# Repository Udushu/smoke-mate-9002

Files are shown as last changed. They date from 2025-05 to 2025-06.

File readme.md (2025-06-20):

# SmokeMATE 

## PARTS

1. Airflow Damper
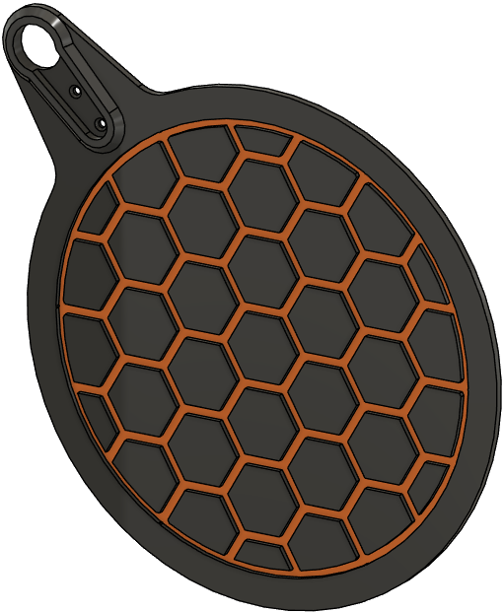
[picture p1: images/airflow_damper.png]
Airflow Damper
 

2. Blower Housing
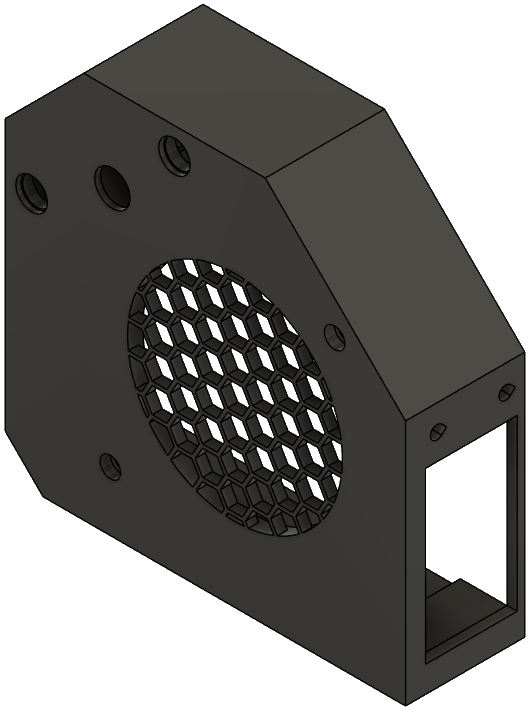
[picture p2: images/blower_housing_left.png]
Blower Housing Left

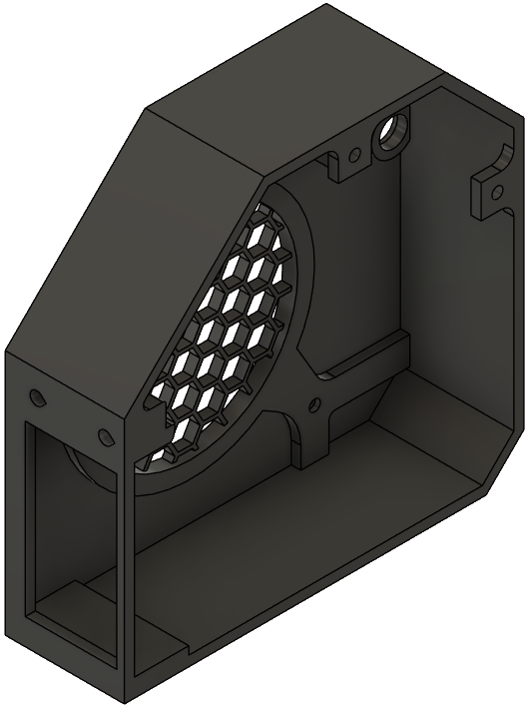
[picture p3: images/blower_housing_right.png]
Blower Housing Right


3. Blower Housing Screw Access Plug
Blower Housing Screw Access Plug

4. Blower Interface Adapter
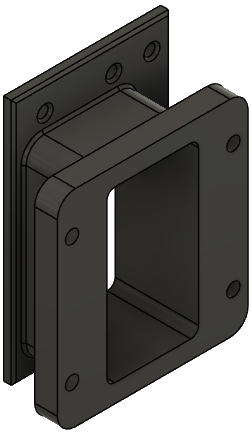
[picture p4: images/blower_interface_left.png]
Blower Interface Adapter Left

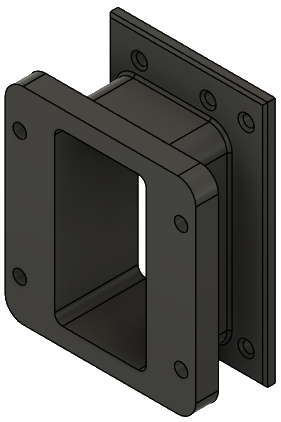
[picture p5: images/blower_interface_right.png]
Blower Interface Adapter Right


5. Control Knob
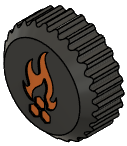
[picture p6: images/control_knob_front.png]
Control Knob Front

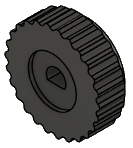
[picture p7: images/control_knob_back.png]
Control Knob Back


6. Display Housing
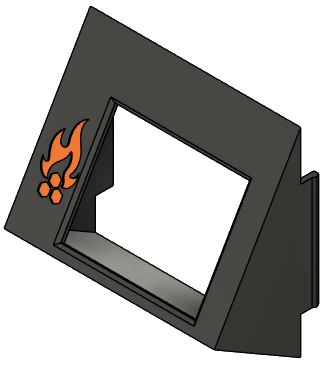
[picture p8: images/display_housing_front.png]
Display Housing Front

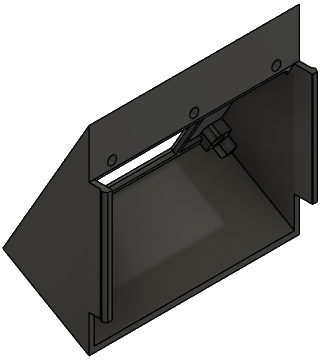
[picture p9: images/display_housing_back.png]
Display Housing Back

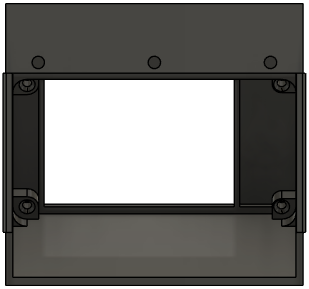
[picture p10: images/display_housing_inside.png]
Display Housing Inside


7. Electronics Housing
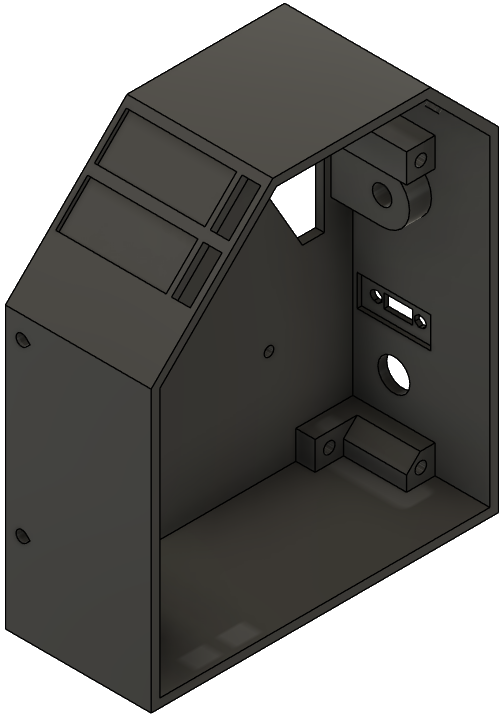
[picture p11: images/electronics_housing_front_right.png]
Electronics Housing Front Right

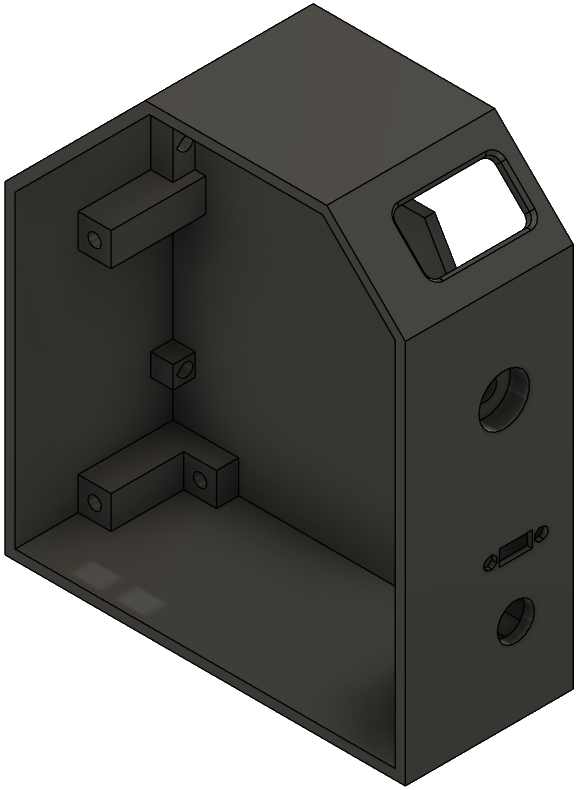
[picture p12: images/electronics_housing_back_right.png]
Electronics Housing Back Right

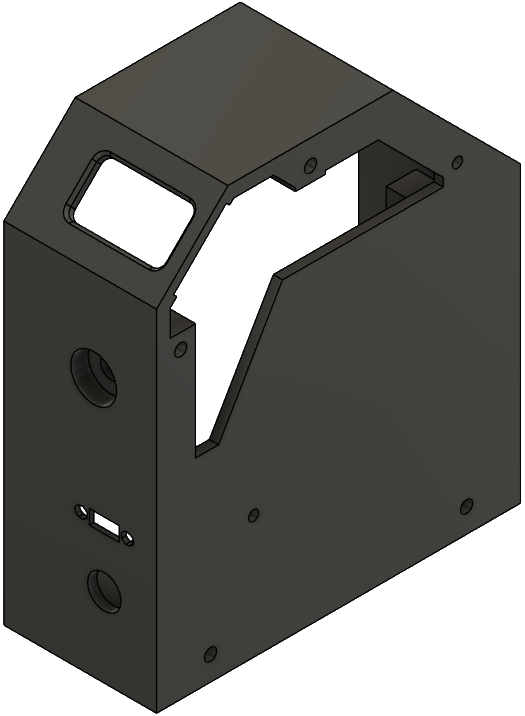
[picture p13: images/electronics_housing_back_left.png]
Electronics Housing Back Left


8. Electronics Lid
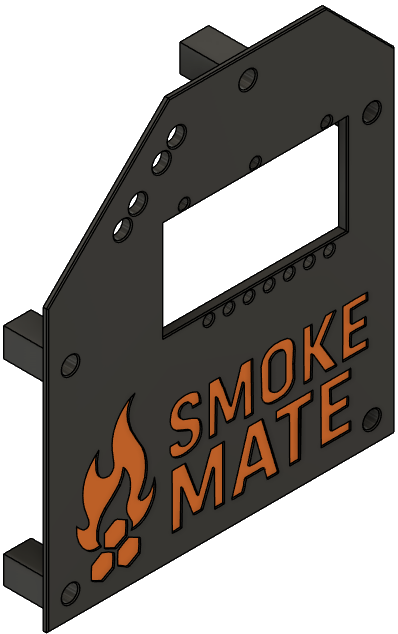
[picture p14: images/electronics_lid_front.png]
Electronics Lid Front

Electronics Lid Back

9. Electronics Mounting Panel
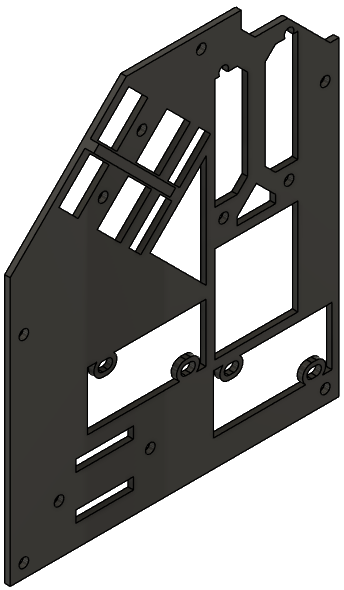
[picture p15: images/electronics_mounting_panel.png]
Electronics Mounting Panel


10. Encoder Access Plug
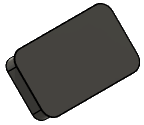
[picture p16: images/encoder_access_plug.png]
Encoder Access Plug


11. Supports
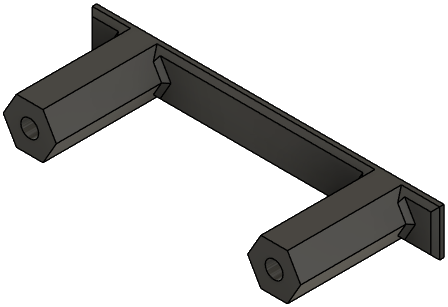
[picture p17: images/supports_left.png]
Supports Left

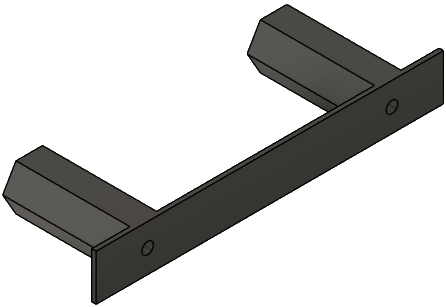
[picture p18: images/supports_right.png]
Supports Right


12. Blower Driver Holders
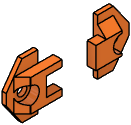
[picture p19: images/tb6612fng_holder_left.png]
Blower Driver Holders Left

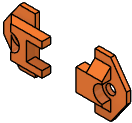
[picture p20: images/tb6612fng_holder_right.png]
Blower Driver Holders Right

Blower Driver Holders Front

13. Thermometer Labels
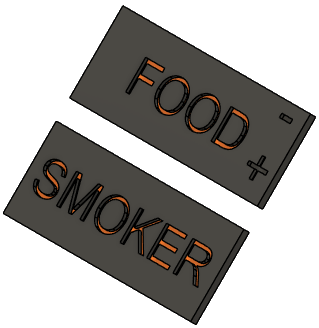
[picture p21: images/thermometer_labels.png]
Thermometer Labels


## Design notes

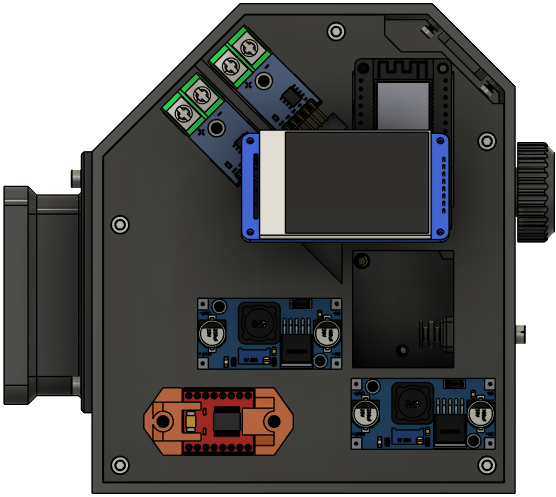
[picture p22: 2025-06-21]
images/smokemate_electronics_with_display.png

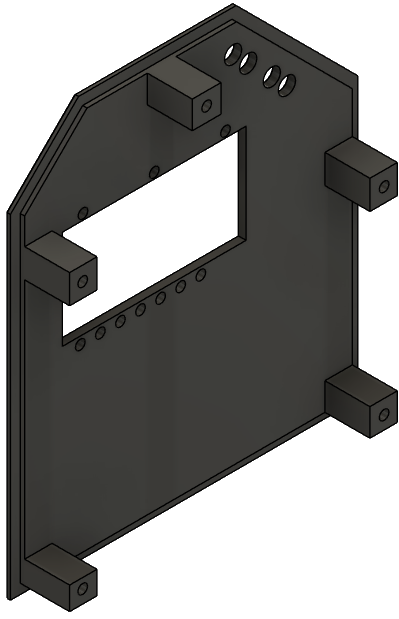
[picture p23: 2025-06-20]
images/electronics_lid_back.png

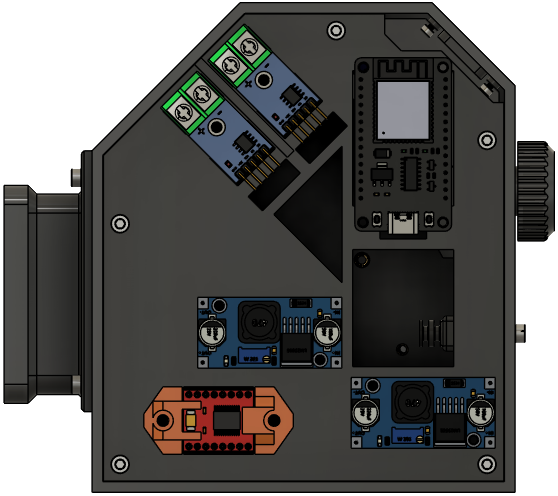
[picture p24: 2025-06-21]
images/smokemate_electronics_no_display.png

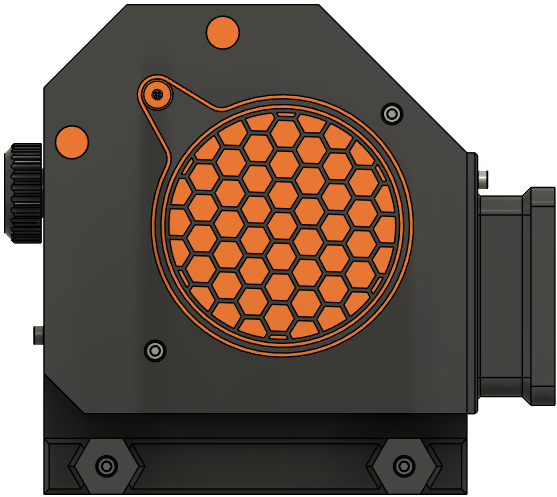
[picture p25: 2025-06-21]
images/smokemate_left.png

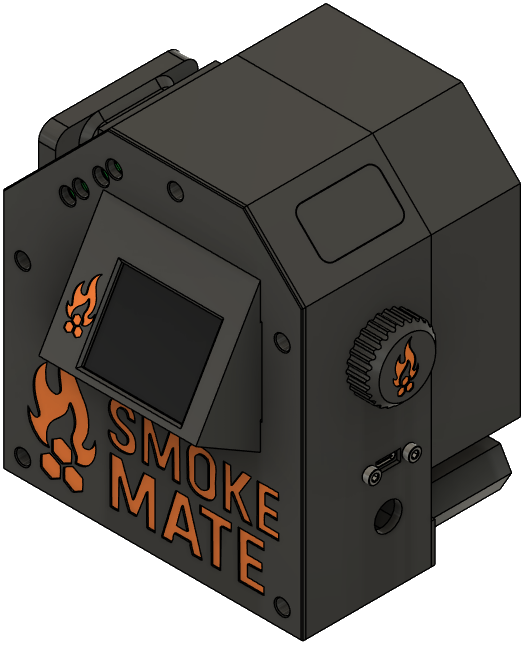
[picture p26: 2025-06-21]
images/smokemate_back_right.png

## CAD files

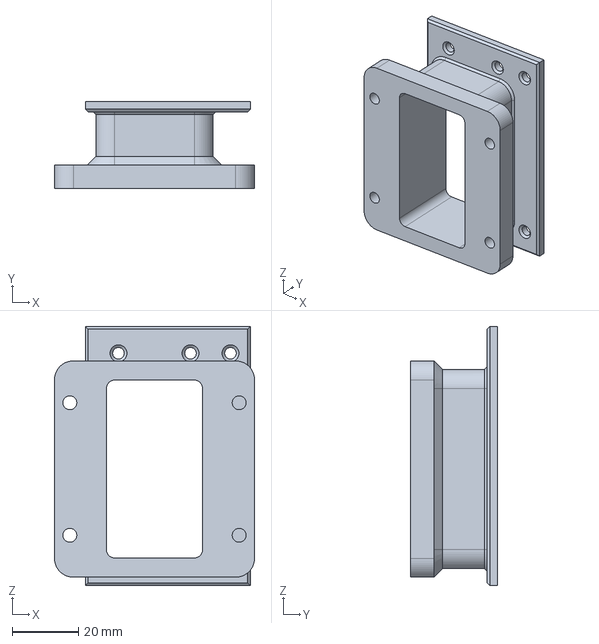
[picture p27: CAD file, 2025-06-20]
hardware/blower_interface.step
60.4 x 26.4 x 78.2 mm

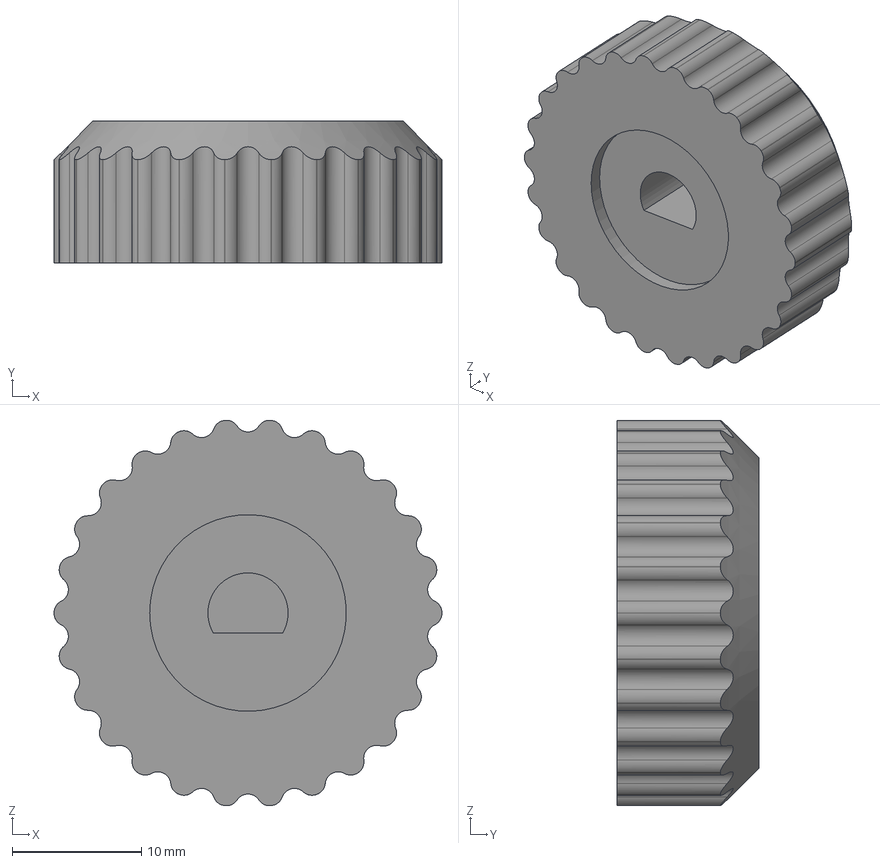
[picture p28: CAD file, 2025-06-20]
hardware/control_knob.step
30.0 x 11.0 x 29.8 mm

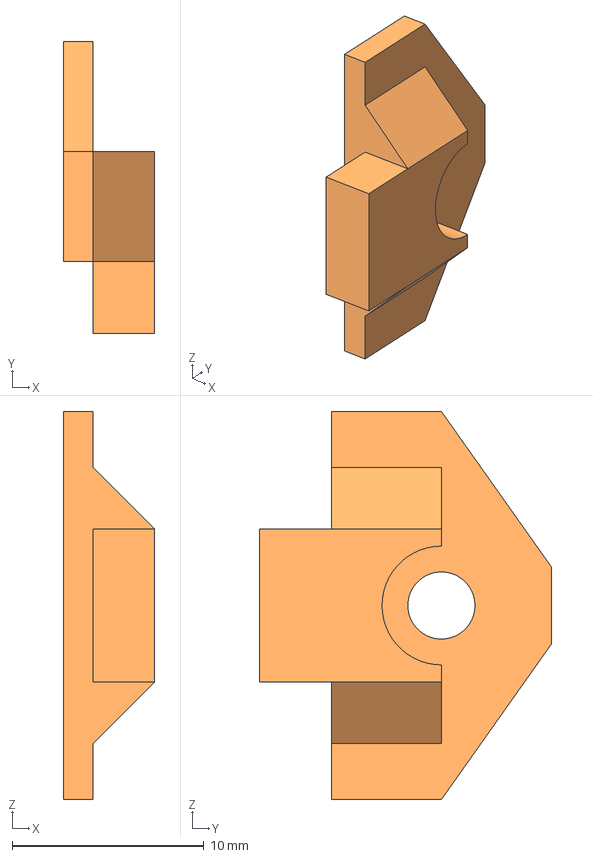
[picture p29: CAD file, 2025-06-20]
hardware/TB6612FNG_holder_right.step
4.75 x 15.3 x 20.2 mm

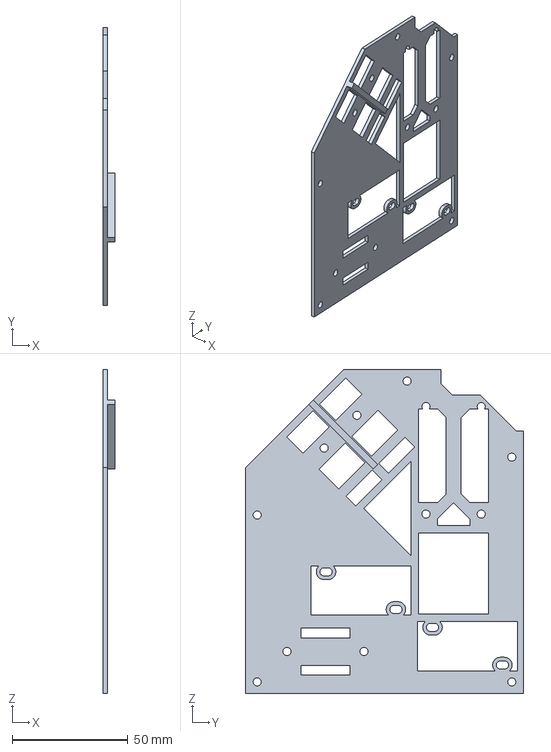
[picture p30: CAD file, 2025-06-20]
hardware/electronics_mounting_panel.step
5.20 x 120.0 x 140.0 mm

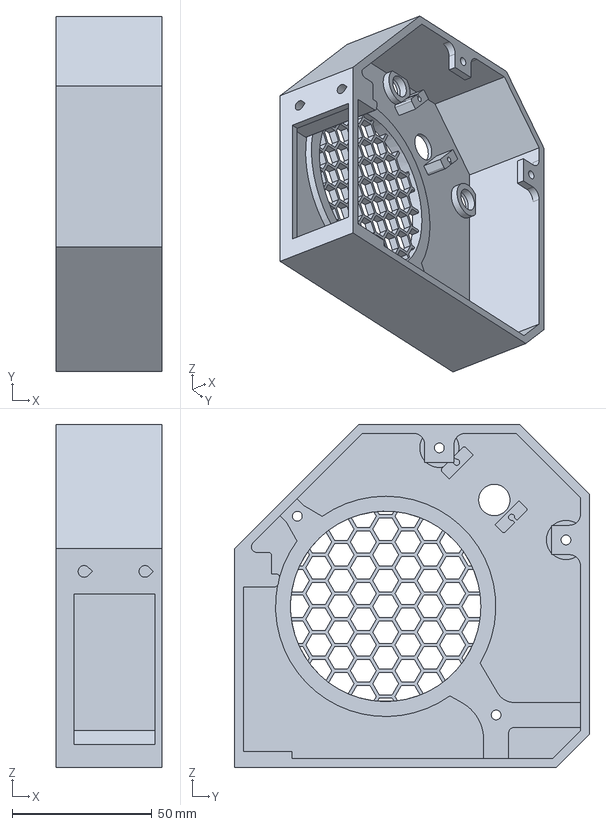
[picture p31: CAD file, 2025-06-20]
hardware/blower_housing.step
37.8 x 126.8 x 122.6 mm

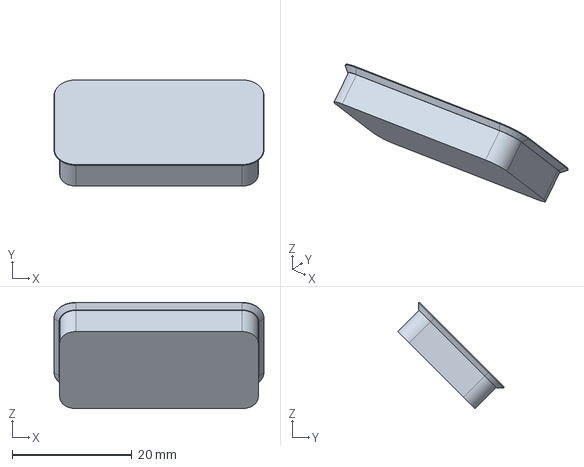
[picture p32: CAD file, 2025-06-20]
hardware/encoder_access_plug.step
35.1 x 17.7 x 17.7 mm

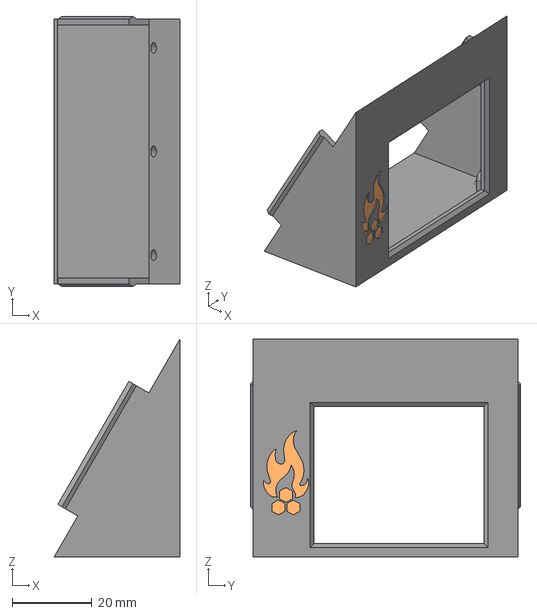
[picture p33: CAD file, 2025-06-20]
hardware/display_housing.step
31.6 x 67.8 x 54.7 mm

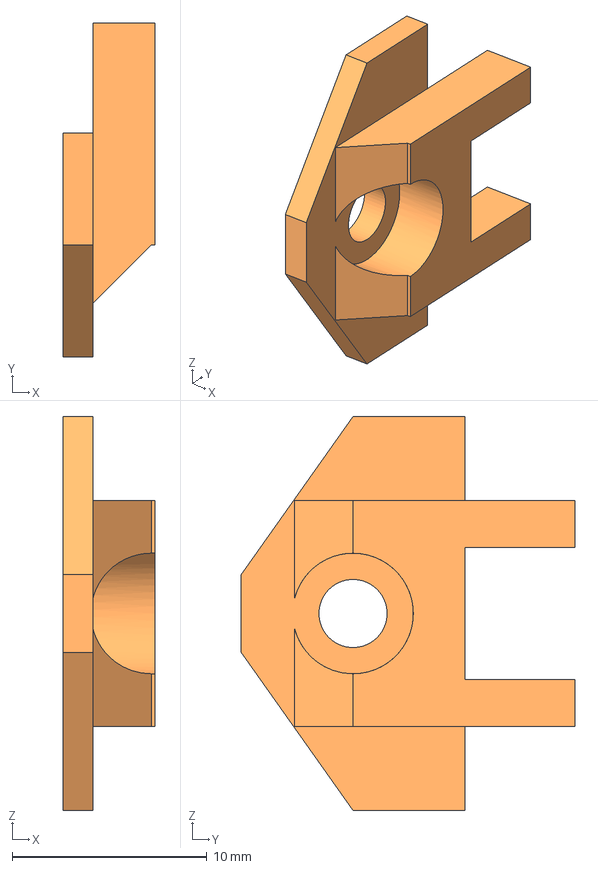
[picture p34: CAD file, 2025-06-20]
hardware/TB6612FNG_holder_left.step
4.75 x 17.2 x 20.2 mm

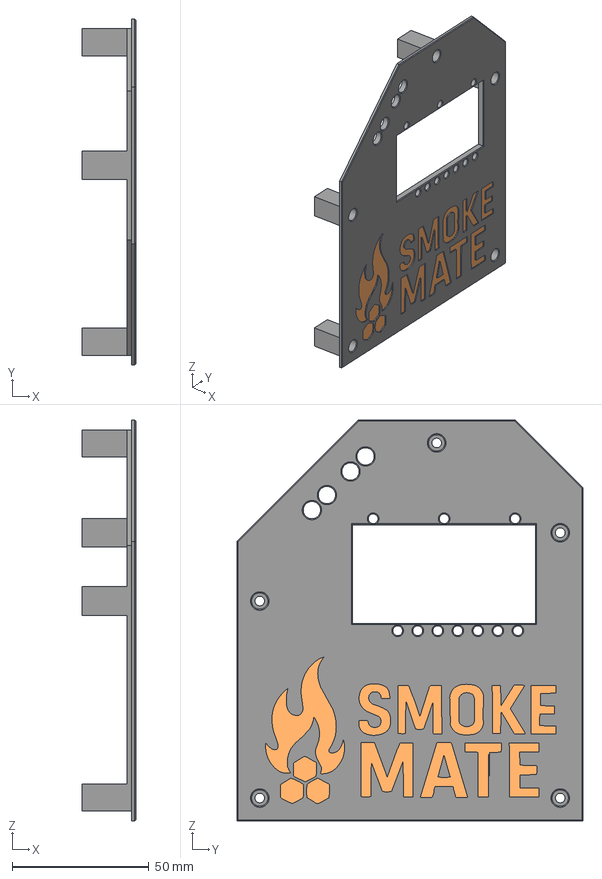
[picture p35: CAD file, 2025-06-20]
hardware/electronics_housing_lid.step
19.6 x 126.8 x 146.8 mm

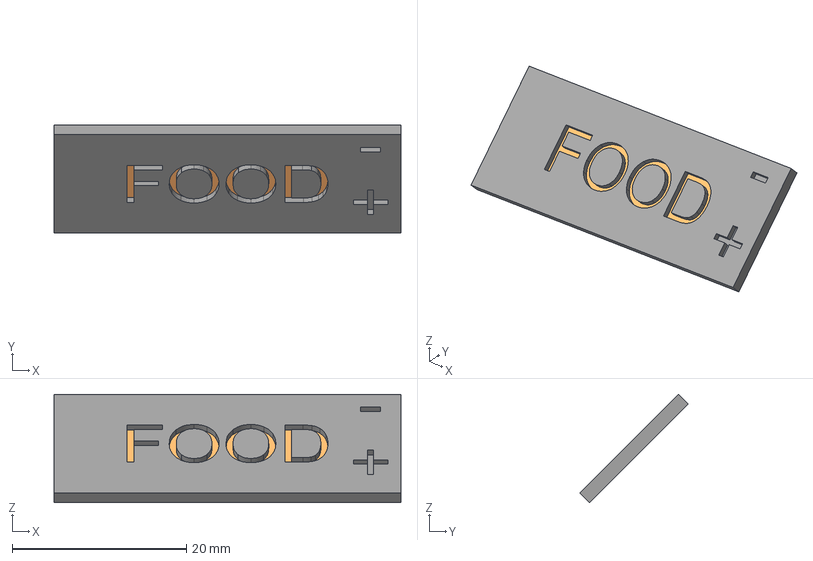
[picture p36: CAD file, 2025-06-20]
hardware/thermometer_label_food.step
39.9 x 12.4 x 12.4 mm

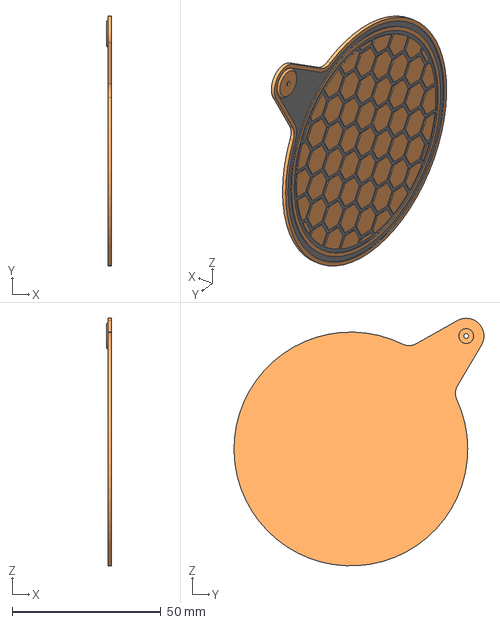
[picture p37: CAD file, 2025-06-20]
hardware/airflow_damper.step
1.80 x 84.1 x 83.3 mm

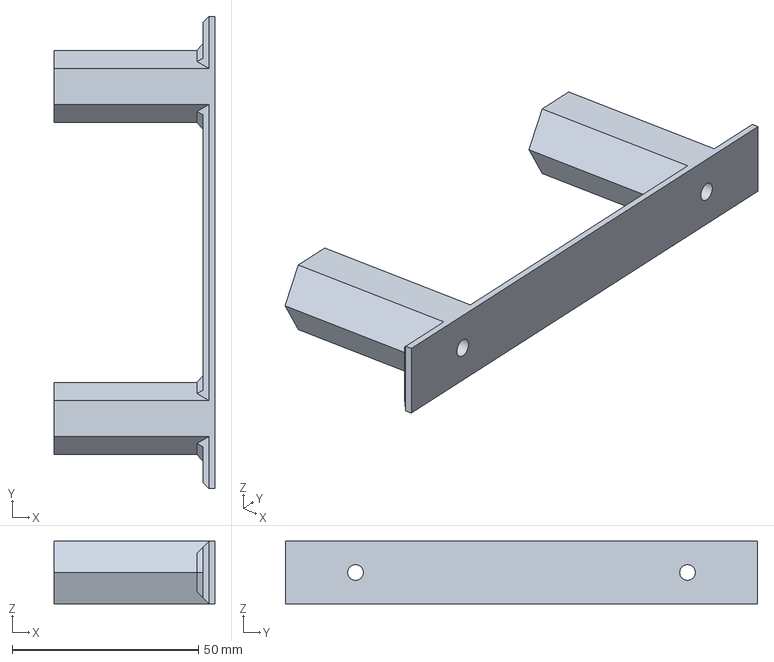
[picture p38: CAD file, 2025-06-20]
hardware/support_feet.step
43.2 x 126.8 x 16.8 mm

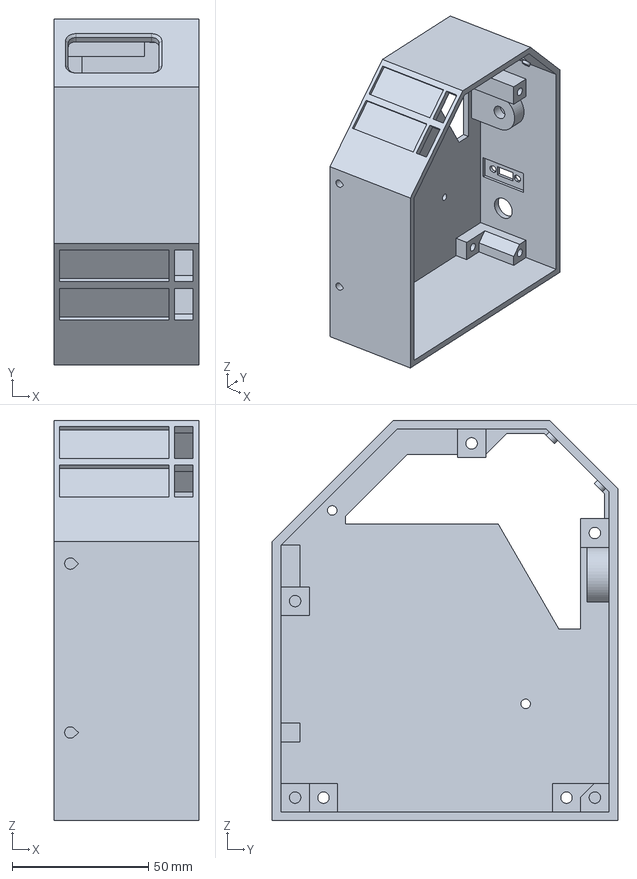
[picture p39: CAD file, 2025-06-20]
hardware/electronics_housing_body.step
53.2 x 126.8 x 146.8 mm

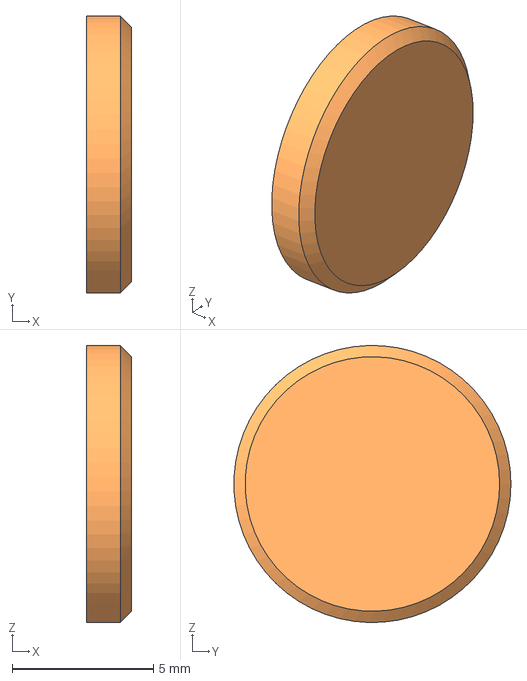
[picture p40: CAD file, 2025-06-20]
hardware/blower_housing_screw_access_plug.step
1.60 x 9.79 x 9.80 mm

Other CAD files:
hardware/thermometer_label_smoker.step

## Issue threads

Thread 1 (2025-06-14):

Antistall on the blower fan

Udushu, 2025-06-14:
The fan could stall at low duty cycle of the PWM drive signal. This was a problem with the previous model. The stalling can be dealt with in several ways:
- Implement a configurable floor value for the fan pwm signal.
- Oscillate fan ever so slightly at low pwm (below some configurable threshold) to nudge it free
- After a pwm value is set, this value is below a configurable threshold, start the fan at a higher safe level instead, and then quickly ramp the pwm down to the demanded level. This should help with the static friction.

Closed 2025-06-17.

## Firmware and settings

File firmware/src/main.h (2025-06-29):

#ifndef MAIN_H
#define MAIN_H

#include <Arduino.h>
#include <Adafruit_GFX.h>
#include <Adafruit_ST7789.h>
#include <SPI.h>
#include <WiFi.h>
#include <ArduinoOTA.h>
#include "types.h"
#include "knob.h"
#include "nvram.h"
#include "thermometer.h"
#include "door.h"
#include "blower.h"
#include "gui.h"
#include "temperaturecontroller.h"
#include "tftdebug.h"
#include "debug.h"
#include "webserver.h"
#include "filtering.h"
#include "mqttclient.h"

// ============================ DEFAULT PASSWORDS =========================
#if __has_include("passwords.h")
#include "passwords.h"
#else
#define NETWORK_SSID ""
#define NETWORK_PASSWORD ""
#endif

// ============================ COMPILATION FLAGS =========================
// #define DEBUG_MAIN
// #define NVRAM_DELETE_ON_STARTUP

// ============================ CONSTANTS =================================
#define WEB_SERVER_PORT 80 // Web server port
#define BAUD_RATE 115200
#define NVRAM_START_ADDRESS 0

#define WIFI_SCAN_TIMEOUT_MSEC 5000 // Timeout for WiFi scan in milliseconds
#define MAX_WIFI_NETWORKS 8         // Maximum number of WiFi networks to store
#define MAX_WIFI_CONNECT_ATTEMPTS 3 // Maximum number of attempts to connect to WiFi

// Default configuration values
#define DEFAULT_TEMPERATURE_TARGET 250
#define DEFAULT_TEMPERATURE_INTERVAL_MSEC 5000
#define DEFAULT_BANG_BANG_THRESHOLD_HIGH 260
#define DEFAULT_BANG_BANG_THRESHOLD_LOW 240
#define DEFAULT_BANG_BANG_HYSTERESIS 5
#define DEFAULT_BANG_BANG_FAN_SPEED 255
#define DEFAULT_DOOR_OPEN_POSITION 110
#define DEFAULT_DOOR_CLOSE_POSITION 4
#define DEFAULT_PID_KP 4.0
#define DEFAULT_PID_KI 0.0
#define DEFAULT_PID_KD 1.0
#define DEFAULT_THERMOMETER_SMOKER_GAIN 1.0
#define DEFAULT_THERMOMETER_SMOKER_OFFSET 0.0
#define DEFAULT_THERMOMETER_FOOD_GAIN 1.0
#define DEFAULT_THERMOMETER_FOOD_OFFSET 0.0
#define DEFAULT_TEMPERATURE_FILTER_ENABLED false
#define DEFAULT_TEMPERATURE_FILTER_COEFF 1.0
#define DEFAULT_MQTT_ENABLED false
#define DEFAULT_MQTT_BROKER "192.168.2.160" // Default MQTT broker hostname
#define DEFAULT_MQTT_PORT 1883
#define DEFAULT_MQTT_USERNAME "smokemate"           // Default MQTT username
#define DEFAULT_MQTT_PASSWORD "12345678"            // Default MQTT password
#define DEFAULT_MQTT_CLIENT_ID "smokemate"          // Default MQTT client ID
#define DEFAULT_MQTT_TOPIC_PREFIX "smoker/backyard" // Default MQTT topic prefix
#define DEFAULT_MQTT_PUBLISH_INTERVAL 10            // in seconds
#define DEFAULT_MQTT_RETAIN true

// ============================ PIN ASSIGNMENTS ===========================
#define PIN_LED 2

// Knob encoder pins
#define PIN_ENCODER_A 25
#define PIN_ENCODER_B 27
#define PIN_ENCODER_BTN 26

// Thermometer pins
#define PIN_THERMOMETER_SO 19        // Shared SO (data out)
#define PIN_THERMOMETER_CLK 15       // Shared Clock (separate from TFT)
#define PIN_THERMOMETER_FOOD_CS 33   // Thermocouple #1 Chip Select
#define PIN_THERMOMETER_SMOKER_CS 32 // Thermocouple #2 Chip Select

// TFT display pins
#define TFT_CS 5
#define TFT_DC 16
#define TFT_RST 17
#define TFT_MOSI 23
#define TFT_SCLK 18
#define TFT_BL 22

// Door servo pins
#define PIN_DOOR_SERVO 21

// Blower motor pins
#define PIN_BLOWER_PWM 14
#define PIN_BLOWER_A 13
#define PIN_BLOWER_B 12
#define PIN_BLOWER_ENABLE 4

// ============================= TFT CONFIGURATION =========================

// TFT display configuration
#define ST7789_DRIVER
#define TFT_WIDTH 240
#define TFT_HEIGHT 320
#define LOAD_GFXFF
#define SPI_FREQUENCY 27000000
#define SPI_READ_FREQUENCY 20000000

// ============================= FUNCTIONS ===================================

void updateGuiState(GuiState &guiState, const ControllerStatus &controllerStatus);
void loadDefaultConfiguration(Configuration *ptr_configuration);
void setupInitializeNVRAM();
void setupInitializeGuiState(GuiState &guiState);
void setupInitializeControllerStatus(ControllerStatus &controllerStatus);
void loopServiceKnobButtonEvents();
void loopUpdateControllerStatus();
void updateConfiguration();
void connectToWiFi();
int calculateTemperatureTarget();

#endif // MAIN_H

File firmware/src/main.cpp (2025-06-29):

#include "main.h"
#include "Arduino.h"

// Timer variables
ulong g_loopTimer500MSec = 0;
ulong g_loopCurrentTimeMSec = 0;

// System configuration
Configuration g_configuration;

// NVRAM definition
NVRAM g_nvram = NVRAM(NVRAM_START_ADDRESS, (uint8_t *)&g_configuration, sizeof(Configuration));

// Knob definition
Knob g_knob = Knob(PIN_ENCODER_A, PIN_ENCODER_B, PIN_ENCODER_BTN, 1000, 50);

// TFT display definition
Adafruit_ST7789 g_tftDisplay = Adafruit_ST7789(TFT_CS, TFT_DC, TFT_RST);
TFTDebug g_tftDebug(&g_tftDisplay, 10, 10, 2);

// Thermometers
Thermometer g_thermometerSmoker(DEFAULT_TEMPERATURE_INTERVAL_MSEC, PIN_THERMOMETER_SMOKER_CS, PIN_THERMOMETER_CLK, PIN_THERMOMETER_SO);
Thermometer g_thermometerFood(DEFAULT_TEMPERATURE_INTERVAL_MSEC, PIN_THERMOMETER_FOOD_CS, PIN_THERMOMETER_CLK, PIN_THERMOMETER_SO);

// Door definition
Door g_door(PIN_DOOR_SERVO, DEFAULT_DOOR_CLOSE_POSITION, DEFAULT_DOOR_OPEN_POSITION);

// Blower motor definition
Blower g_blowerMotor(PIN_BLOWER_PWM, PIN_BLOWER_A, PIN_BLOWER_B, PIN_BLOWER_ENABLE);

// Initalie the interface
SmokeMateGUI g_smokeMateGUI(g_tftDisplay, g_configuration);

// Device status
ControllerStatus g_controllerStatus; // Controller status
bool g_prevIsRunning = false;        // Previous running state for the controller

// Temperature Controller
TemperatureController g_temperatureController(g_controllerStatus, g_configuration, g_blowerMotor, g_door);

// Webserver
WebServer g_webServer = WebServer(WEB_SERVER_PORT, g_controllerStatus, g_configuration);
bool g_prevWiFiConnected = false;                      // Previous WiFi connected state for the controller
int g_wiFiConnectAttempts = MAX_WIFI_CONNECT_ATTEMPTS; // Maximum number of attempts to connect to WiFi

// Temperature profiling variables
int g_temperatureProfileStepIndex = -1;      // Current step index in the temperature profile, -1 means no active profile
ulong g_temperatureProfileStartTimeMSec = 0; // Start time of the current temperature profile step

Filter g_temperatureFilter(FilterType::NONE, DEFAULT_TEMPERATURE_FILTER_COEFF, 0.0f); // Temperature filter

// MQTT client
SmokeMatesMqttClient g_mqttClient(g_configuration, g_controllerStatus);

void setup()
{

  // Blink LED to indicate startup
  pinMode(PIN_LED, OUTPUT);
  digitalWrite(PIN_LED, HIGH); // Turn on LED
  delay(500);

  // Set up SPI manually if needed (ESP32 hardware SPI)
  SPI.begin(TFT_SCLK, -1, TFT_MOSI, TFT_CS);

  // Initalize TFT display
  g_tftDisplay.init(240, 320);
  g_tftDisplay.setRotation(1);
  g_tftDisplay.fillScreen(ST77XX_BLACK);

  // Initialize debug output on TFT
  pinMode(TFT_BL, OUTPUT);
  digitalWrite(TFT_BL, HIGH);

  // Initialize debug output
  g_tftDebug.clear();
  Serial.begin(BAUD_RATE);

  // Initialize NVRAM
  setupInitializeNVRAM();

  // Initialize the door
  g_door.begin();
  g_door.setBoundaries(g_configuration.doorClosePosition, g_configuration.doorOpenPosition);
  g_door.close();
  while (g_door.isMoving())
  {
  }

  // Initialize the blower motor
  g_blowerMotor.setPWM(0);

  // Initalize the interface
  g_smokeMateGUI.begin();

  // Initialize the thermometers
  g_thermometerSmoker.setSimulated(g_configuration.isThemometerSimulated);
  g_thermometerFood.setSimulated(g_configuration.isThemometerSimulated);

  if (g_configuration.isWiFiEnabled)
  {
    // If WiFi is enabled, attempt to connect
    DEBUG_PRINTLN("WiFi is enabled, attempting to connect...");
    connectToWiFi();
    if (g_controllerStatus.isWiFiConnected)
    {
      DEBUG_PRINTLN("WiFi connected successfully.");
      g_webServer.begin(); // Start the web server

      if (g_configuration.isMqttEnabled)
      {
        // Set MQTT broker to "test.mosquitto.org" for testing

        strncpy(g_configuration.mqttBroker, DEFAULT_MQTT_BROKER, sizeof(g_configuration.mqttBroker) - 1);
        g_configuration.mqttBroker[sizeof(g_configuration.mqttBroker) - 1] = '\0';

        strncpy(g_configuration.mqttClientId, DEFAULT_MQTT_CLIENT_ID, sizeof(g_configuration.mqttClientId) - 1);
        g_configuration.mqttClientId[sizeof(g_configuration.mqttClientId) - 1] = '\0';

        strncpy(g_configuration.mqttTopicPrefix, DEFAULT_MQTT_TOPIC_PREFIX, sizeof(g_configuration.mqttTopicPrefix) - 1);
        g_configuration.mqttTopicPrefix[sizeof(g_configuration.mqttTopicPrefix) - 1] = '\0';
        g_configuration.mqttPublishInterval = DEFAULT_MQTT_PUBLISH_INTERVAL; // Set default publish interval

        strncpy(g_configuration.mqttUsername, DEFAULT_MQTT_USERNAME, sizeof(g_configuration.mqttUsername) - 1);
        g_configuration.mqttUsername[sizeof(g_configuration.mqttUsername) - 1] = '\0';
        strncpy(g_configuration.mqttPassword, DEFAULT_MQTT_PASSWORD, sizeof(g_configuration.mqttPassword) - 1);
        g_configuration.mqttPassword[sizeof(g_configuration.mqttPassword) - 1] = '\0';

        g_mqttClient.begin();
      }
    }
  }

  digitalWrite(PIN_LED, LOW); // Turn off LED - setup is now done
}

void loop()
{

  ArduinoOTA.handle();

  // Get the current time in milliseconds
  g_loopCurrentTimeMSec = millis();

  // ====== SERVICE ALL COMPONENTS THAT RUN AT THE CPU RATE

  // Service the knob
  g_knob.service(g_loopCurrentTimeMSec);

  // Service the thermometers
  g_thermometerSmoker.service(g_loopCurrentTimeMSec);
  g_thermometerFood.service(g_loopCurrentTimeMSec);

  // Service the door and blower
  g_door.service(g_loopCurrentTimeMSec);
  g_blowerMotor.service(g_loopCurrentTimeMSec);

  // Service the mqtt client
  if (g_configuration.isMqttEnabled && g_controllerStatus.isWiFiConnected)
  {
    g_mqttClient.service(g_loopCurrentTimeMSec);
  }

  loopServiceKnobButtonEvents();
  loopUpdateControllerStatus();
  updateConfiguration();

  // Do actions on the controller status change
  if (g_controllerStatus.isRunning != g_prevIsRunning)
  {
    // if the controller just stopped close the door and stop the blower motor
    if (!g_controllerStatus.isRunning && g_prevIsRunning)
    {
      // Stop the blower motor
      g_blowerMotor.setPWM(0);
      // Close the door
      g_door.close();
    }
    else if (g_controllerStatus.isRunning && !g_prevIsRunning)
    {
      // If the controller just started, set the start time
      g_controllerStatus.controllerStartMSec = g_loopCurrentTimeMSec;
      // Reset the temperature profile step index
      g_temperatureProfileStepIndex = -1; // Reset the temperature profile step index
    }
    g_prevIsRunning = g_controllerStatus.isRunning; // Update the previous running state
  }

  // Service the temperature controller
  if (g_controllerStatus.isRunning && g_thermometerSmoker.isNewTemperatureAvailable())
  {
    // Update the target temperature
    g_controllerStatus.temperatureTarget = calculateTemperatureTarget();
    // If the controller is not running, we still want to update the temperature
    g_temperatureController.service(g_temperatureFilter.update(g_thermometerSmoker.getTemperatureF()), g_loopCurrentTimeMSec);
    g_controllerStatus.temperatureError = g_temperatureController.getLastOutput(); // Get the last output from the temperature controller
  }

  if (!g_controllerStatus.isRunning && g_configuration.isForcedDoorPosition)
  {
    g_door.setPosition(g_configuration.forcedDoorPosition); // Set the door position if forced
  }

  if (!g_controllerStatus.isRunning && g_configuration.isForcedFanPWM)
  {
    g_blowerMotor.setPWM(g_configuration.forcedFanPWM); // Set the blower motor PWM if forced
  }

  // Check nvram save request
  if (g_webServer.isNVRAMSaveRequired())
  {
    g_nvram.writeNVRAM(); // Write the configuration to NVRAM
  }

  // Check the 0.5 second timer
  if (g_loopCurrentTimeMSec - g_loopTimer500MSec >= 500)
  {
    g_loopTimer500MSec = g_loopCurrentTimeMSec;

    // Update GUI state
    g_smokeMateGUI.updateState(g_controllerStatus, g_configuration);
    g_smokeMateGUI.service(g_loopCurrentTimeMSec);
    // Check if the gui requested NVRAM save
    if (g_smokeMateGUI.isNVRAMSaveRequired())
    {
      g_nvram.writeNVRAM(); // Write the configuration to NVRAM
    }

    // Update the wifi status
    if (g_configuration.isWiFiEnabled)
    {
      g_controllerStatus.RSSI = WiFi.RSSI();
      g_controllerStatus.bars = WiFi.RSSI() / -20; // Convert RSSI to bars (0-5)

      // --- WiFi/server auto-reconnect logic ---
      if (g_prevWiFiConnected &&
          !g_controllerStatus.isWiFiConnected &&
          g_wiFiConnectAttempts < MAX_WIFI_CONNECT_ATTEMPTS)
      {
        // Lost connection, try to reconnect and restart server
        DEBUG_PRINTLN("WiFi connection lost, attempting to reconnect...");
        connectToWiFi();
        if (g_controllerStatus.isWiFiConnected)
        {
          DEBUG_PRINTLN("WiFi reconnected, restarting web server...");
          g_webServer.begin();
          g_wiFiConnectAttempts = 0; // Reset the connection attempts
        }
        else
        {
          g_wiFiConnectAttempts++; // Increment the connection attempts
          DEBUG_PRINTLN("WiFi reconnect attempt failed, retrying...");
        }
      }
      g_prevWiFiConnected = g_controllerStatus.isWiFiConnected;
    }
  }
}

void loopServiceKnobButtonEvents()
{
  if (g_knob.isShortButtonPressed())
  {
    g_smokeMateGUI.commandSelect(); // Handle short button press
  }

  // Check for the long press on the knob
  if (g_knob.isLongButtonPressed())
  {
    // Check on the current GUI state
    if (g_smokeMateGUI.getState().header.state == GUI_STATE_HEADER_STATUS ||
        g_smokeMateGUI.getState().header.state == GUI_STATE_HEADER_CHART ||
        g_smokeMateGUI.getState().header.state == GUI_STATE_HEADER_SETTINGS)
    {
      // Toggle the controller running state
      g_controllerStatus.isRunning = !g_controllerStatus.isRunning;
      if (g_controllerStatus.isRunning)
      {
        // Start the controller
        g_controllerStatus.controllerStartMSec = g_loopCurrentTimeMSec;
        // g_blowerMotor.start(); // Start the blower motor
      }
      else
      {
        // Stop the controller
        // g_blowerMotor.stop(); // Stop the blower motor
      }
    }
    else
    {
      g_smokeMateGUI.commandConfirm(); // Handle long button press in settings edit mode
    }
  }

  if (g_knob.isUltraLongButtonPressed())
  {
    // Reset ESP32 and NVRAM
    g_tftDisplay.fillScreen(ST77XX_BLACK); // Clear the display
    DEBUG_PRINTLN("Ultra long button press detected, clearing NVRAM resetting ESP32");
    g_nvram.clearNVRAM(); // Clear NVRAM
    delay(1000);          // Wait for a second to ensure NVRAM is cleared
    ESP.restart();        // Restart the ESP32
  }

  if (g_knob.isRotatingUp())
  {
    // Increase the target temperature
    g_smokeMateGUI.commandMoveNext();
  }

  if (g_knob.isRotatingDown())
  {
    // Decrease the target temperature
    g_smokeMateGUI.commandMovePrevious();
  }
}

void updateConfiguration()
{
  g_thermometerSmoker.setSimulated(g_configuration.isThemometerSimulated);
  g_thermometerFood.setSimulated(g_configuration.isThemometerSimulated);
  g_temperatureFilter.setType(g_configuration.isTemperatureFilterEnabled ? FilterType::EWMA : FilterType::NONE,
                              g_configuration.temperatureFilterCoeff);
}

void loopUpdateControllerStatus()
{
  // Update the status variable of the controller
  g_controllerStatus.temperatureSmoker = g_thermometerSmoker.getTemperatureF();
  g_controllerStatus.temperatureFood = g_thermometerFood.getTemperatureF();
  g_controllerStatus.fanPWM = g_blowerMotor.getPWM();
  g_controllerStatus.doorPosition = g_door.getPosition();
  g_controllerStatus.uptime = g_loopCurrentTimeMSec;
  // g_controllerStatus.RSSI = WiFi.RSSI();
  // g_controllerStatus.bars = WiFi.RSSI() / -20;             // Convert RSSI to bars (0-5)
  g_controllerStatus.isWiFiConnected = WiFi.isConnected(); // Update WiFi connection status
  if (!g_controllerStatus.isRunning)
  {
    if (g_configuration.isTemperatureProfilingEnabled && g_configuration.temperatureProfileStepsCount > 0)
    {
      g_controllerStatus.temperatureTarget = g_configuration.temperatureProfile[0].temperatureStartF; // Set target temperature to the first profile step
    }
    else
    {
      g_controllerStatus.temperatureTarget = g_configuration.temperatureTarget; // Set target temperature to the configured value
    }
  }

  int temperatureProfileisRunning = 0;
  if (g_temperatureProfileStepIndex == -1)
  {
    temperatureProfileisRunning = 0; // No active profile step, profile is not running
  }
  else if (g_temperatureProfileStepIndex >= 0 &&
           g_temperatureProfileStepIndex < g_configuration.temperatureProfileStepsCount)
  {
    temperatureProfileisRunning = 1; // Profile is running
  }
  else
  {
    temperatureProfileisRunning = 2; // Profile finished
  }
  g_controllerStatus.isProfileRunning = temperatureProfileisRunning;
  g_controllerStatus.temperatureProfileStepIndex = g_temperatureProfileStepIndex;                 // Current step index in the temperature profile
  g_controllerStatus.temperatureProfileStartTimeMSec = g_temperatureProfileStartTimeMSec;         // Start time of the current temperature profile step
  g_controllerStatus.temperatureProfileStepsCount = g_configuration.temperatureProfileStepsCount; // Number of steps in the temperature profile
  if (g_temperatureProfileStepIndex >= 0 && g_temperatureProfileStepIndex < g_configuration.temperatureProfileStepsCount)
  {
    g_controllerStatus.temperatureProfileStepType = g_configuration.temperatureProfile[g_temperatureProfileStepIndex].type; // Type of the current temperature profile step
  }
  else
  {
    g_controllerStatus.temperatureProfileStepType = TEMP_PROFILE_TYPE_DWELL; // Default to dwell type if no active profile step
  }
}

void setupInitializeControllerStatus(ControllerStatus &controllerStatus)
{
  controllerStatus.isRunning = false;                                     // Start with controller not running
  controllerStatus.uuid = "00000000-0000-0000-0000-000000000000";         // Default UUID
  controllerStatus.uptime = 0;                                            // Start with zero uptime
  controllerStatus.controllerStartMSec = 0;                               // Set controller start time
  controllerStatus.temperatureSmoker = 0;                                 // Start with zero smoker temperature
  controllerStatus.temperatureFood = 0;                                   // Start with zero food temperature
  controllerStatus.temperatureTarget = g_configuration.temperatureTarget; // Set target temperature from configuration
  controllerStatus.fanPWM = 0;                                            // Start with fan off
  controllerStatus.doorPosition = 0;                                      // Get initial door position
  controllerStatus.RSSI = 0;                                              // Start with zero RSSI
  controllerStatus.bars = 0;                                              // Start with zero bars
}

void loadDefaultConfiguration(Configuration *ptr_configuration)
{
  ptr_configuration->temperatureTarget = DEFAULT_TEMPERATURE_TARGET;
  ptr_configuration->temperatureIntervalMSec = DEFAULT_TEMPERATURE_INTERVAL_MSEC;

  ptr_configuration->isTemperatureProfilingEnabled = false; // Start with temperature profiling disabled
  ptr_configuration->temperatureProfileStepsCount = 0;      // Start with no temperature profile steps
  for (int i = 0; i < MAX_PROFILE_STEPS; i++)
  {
    ptr_configuration->temperatureProfile[i].timeMSec = 1000;
    ptr_configuration->temperatureProfile[i].type = TEMP_PROFILE_TYPE_DWELL;                 // Default to dwell type
    ptr_configuration->temperatureProfile[i].temperatureStartF = DEFAULT_TEMPERATURE_TARGET; // Default to target temperature
    ptr_configuration->temperatureProfile[i].temperatureEndF = DEFAULT_TEMPERATURE_TARGET;   // Default to target temperature
  }

  ptr_configuration->isPIDEnabled = true;
  ptr_configuration->kP = DEFAULT_PID_KP;
  ptr_configuration->kI = DEFAULT_PID_KI;
  ptr_configuration->kD = DEFAULT_PID_KD;

  ptr_configuration->bangBangLowThreshold = DEFAULT_BANG_BANG_THRESHOLD_LOW;
  ptr_configuration->bangBangHighThreshold = DEFAULT_BANG_BANG_THRESHOLD_HIGH;
  ptr_configuration->bangBangHysteresis = DEFAULT_BANG_BANG_HYSTERESIS;
  ptr_configuration->bangBangFanSpeed = DEFAULT_BANG_BANG_FAN_SPEED;

  ptr_configuration->doorOpenPosition = DEFAULT_DOOR_OPEN_POSITION;
  ptr_configuration->doorClosePosition = DEFAULT_DOOR_CLOSE_POSITION;

  ptr_configuration->themometerSmokerGain = DEFAULT_THERMOMETER_SMOKER_GAIN;
  ptr_configuration->themometerSmokerOffset = DEFAULT_THERMOMETER_SMOKER_OFFSET;
  ptr_configuration->themometerFoodGain = DEFAULT_THERMOMETER_FOOD_GAIN;
  ptr_configuration->themometerFoodOffset = DEFAULT_THERMOMETER_FOOD_OFFSET;

  ptr_configuration->isThemometerSimulated = false; // Start with real thermometers

  ptr_configuration->isForcedFanPWM = false;
  ptr_configuration->forcedFanPWM = DEFAULT_BANG_BANG_FAN_SPEED;
  ptr_configuration->isForcedDoorPosition = false;
  ptr_configuration->forcedDoorPosition = 0;

  ptr_configuration->isWiFiEnabled = false;                                                    // Start with WiFi disabled
  strncpy(ptr_configuration->wifiSSID, NETWORK_SSID, sizeof(ptr_configuration->wifiSSID) - 1); // Default SSID
  ptr_configuration->wifiSSID[sizeof(ptr_configuration->wifiSSID) - 1] = '\0';
  strncpy(ptr_configuration->wifiPassword, NETWORK_PASSWORD, sizeof(ptr_configuration->wifiPassword) - 1); // Default password
  ptr_configuration->wifiPassword[sizeof(ptr_configuration->wifiPassword) - 1] = '\0';

  ptr_configuration->isTemperatureFilterEnabled = DEFAULT_TEMPERATURE_FILTER_ENABLED; // Default temperature filter enabled
  ptr_configuration->temperatureFilterCoeff = DEFAULT_TEMPERATURE_FILTER_COEFF;       // Default temperature filter coefficient

  ptr_configuration->isMqttEnabled = DEFAULT_MQTT_ENABLED;                                                // Default MQTT enabled
  strncpy(ptr_configuration->mqttBroker, DEFAULT_MQTT_BROKER, sizeof(ptr_configuration->mqttBroker) - 1); // Default MQTT broker
  ptr_configuration->mqttBroker[sizeof(ptr_configuration->mqttBroker) - 1] = '\0';
  ptr_configuration->mqttPort = DEFAULT_MQTT_PORT;                                                              // Default MQTT port
  strncpy(ptr_configuration->mqttUsername, DEFAULT_MQTT_USERNAME, sizeof(ptr_configuration->mqttUsername) - 1); // Default MQTT username
  ptr_configuration->mqttUsername[sizeof(ptr_configuration->mqttUsername) - 1] = '\0';
  strncpy(ptr_configuration->mqttPassword, DEFAULT_MQTT_PASSWORD, sizeof(ptr_configuration->mqttPassword) - 1); // Default MQTT password
  ptr_configuration->mqttPassword[sizeof(ptr_configuration->mqttPassword) - 1] = '\0';
  strncpy(ptr_configuration->mqttClientId, DEFAULT_MQTT_CLIENT_ID, sizeof(ptr_configuration->mqttClientId) - 1); // Default MQTT client ID
  ptr_configuration->mqttClientId[sizeof(ptr_configuration->mqttClientId) - 1] = '\0';
  strncpy(ptr_configuration->mqttTopicPrefix, DEFAULT_MQTT_TOPIC_PREFIX, sizeof(ptr_configuration->mqttTopicPrefix) - 1); // Default MQTT topic prefix
  ptr_configuration->mqttTopicPrefix[sizeof(ptr_configuration->mqttTopicPrefix) - 1] = '\0';
  ptr_configuration->mqttPublishInterval = DEFAULT_MQTT_PUBLISH_INTERVAL; // Default MQTT publish interval
  ptr_configuration->isMqttRetain = DEFAULT_MQTT_RETAIN;                  // Default MQTT retain flag
}

void setupInitializeNVRAM()
{
  bool result;
  result = g_nvram.initNVRAM(); // Initialize NVRAM
#ifdef DEBUG_MAIN
  if (!result)
  {
    DEBUG_PRINTLN();
    DEBUG_PRINTLN("Failed to INIT NVRAM");
  }
  else
  {
    DEBUG_PRINTLN();
    DEBUG_PRINTLN("NVRAM INIT success");
  }
#endif
#ifdef NVRAM_DELETE_ON_STARTUP
  g_nvram.clearNVRAM(); // Clear NVRAM on startup
#ifdef DEBUG_MAIN
  DEBUG_PRINTLN();
  DEBUG_PRINTLN("NVRAM cleared on startup");
#endif
  loadDefaultConfiguration(&g_configuration); // Load default configuration
#ifdef DEBUG_MAIN
  DEBUG_PRINTLN();
  DEBUG_PRINTLN("Dflt config loaded");
#endif
#endif
  result = g_nvram.readNVRAM(); // Read NVRAM
  if (!result)
  {

#ifdef DEBUG_MAIN
    DEBUG_PRINTLN();
    DEBUG_PRINTLN("Failed to READ NVRAM");
    DEBUG_PRINTLN("Loading DFLT config");
#endif
    loadDefaultConfiguration(&g_configuration); // Load default configuration
#ifdef DEBUG_MAIN
    DEBUG_PRINTLN();
    DEBUG_PRINTLN("WRT DFLT config to NVRAM");
#endif
    delay(1000);
    result = g_nvram.writeNVRAM();
#ifdef DEBUG_MAIN
    DEBUG_PRINTLN(result ? "SUCCESS WRT to NVRAM" : "FAILED WRT to NVRAM");
    delay(1000);
#endif
  }
  else
  {
#ifdef DEBUG_MAIN
    DEBUG_PRINTLN("NVRAM READ success");
#endif
  }
}
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

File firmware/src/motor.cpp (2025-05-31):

#include "motor.h"

Motor::Motor() : m_pinPWM(0), m_pinA(0), m_pinB(0) {}

Motor::Motor(uint pinPWM, uint pinA, uint pinB, uint enb) : m_pinPWM(pinPWM),
                                                            m_pinA(pinA),
                                                            m_pinB(pinB),
                                                            m_pinEnb(enb)
{
    pinMode(m_pinPWM, OUTPUT);
    pinMode(m_pinA, OUTPUT);
    pinMode(m_pinB, OUTPUT);
    pinMode(m_pinEnb, OUTPUT);

    m_state = MOTOR_STATE_IDLE;
    m_pwm = 255;

    // initialize the motor id with string of spaces
    for (int i = 0; i < 12; i++)
    {
        m_id[i] = ' ';
    }
}

void Motor::open()
{
#ifdef DEBUG_MOTOR
    // Print motor id string, function name and pwm value
    Serial.print(m_id);
    Serial.print(" Motor::open() -> PWM:");
    Serial.println(m_pwm);
#endif
    digitalWrite(m_pinEnb, HIGH); // Enable the motor
    analogWrite(m_pinPWM, m_pwm);
    digitalWrite(m_pinA, HIGH);
    digitalWrite(m_pinB, LOW);
    m_state = MOTOR_STATE_OPEN;
}

void Motor::close()
{
#ifdef DEBUG_MOTOR
    // Print motor id string, function name and pwm value
    Serial.print(m_id);
    Serial.print(" Motor::close() -> PWM:");
    Serial.println(m_pwm);
#endif
    digitalWrite(m_pinEnb, LOW); // Enable the motor
    analogWrite(m_pinPWM, m_pwm);
    digitalWrite(m_pinA, LOW);
    digitalWrite(m_pinB, HIGH);
    m_state = MOTOR_STATE_CLOSE;
}

void Motor::stop()
{
#ifdef DEBUG_MOTOR
    // Print motor id string and function name
    Serial.print(m_id);
    Serial.println(" Motor::stop()");
#endif
    analogWrite(m_pinPWM, 0);
    digitalWrite(m_pinA, LOW);
    digitalWrite(m_pinB, LOW);
    m_state = MOTOR_STATE_IDLE;
}

MotorState Motor::getState()
{
    return m_state;
}

void Motor::setPWM(uint pwm)
{
#ifdef DEBUG_MOTOR
    Serial.print(m_id);
    Serial.print(" Motor::setPWM() -> PWM:");
    Serial.println(pwm);
#endif
    m_pwm = pwm;
}

uint Motor::getPWM()
{
    return m_pwm;
}

void Motor::setID(const char *id)
{
    strncpy(m_id, id, 12);
    m_id[12] = '\0';
}

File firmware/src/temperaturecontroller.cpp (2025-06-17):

#include "temperaturecontroller.h"

TemperatureController::TemperatureController(ControllerStatus &status, Configuration &config, Blower &blower, Door &door)
    : m_status(status), m_config(config), m_blower(blower), m_door(door),
      m_algorithm(CONTROL_PID), m_pid(config.kP, config.kI, config.kD, config.temperatureIntervalMSec),
      m_bangBang(config.bangBangLowThreshold, config.bangBangHighThreshold, config.bangBangHysteresis)
{
    m_lastServiceTimeMSec = 0;
    m_pid.enable(); // Enable PID controller by default
    m_lastOutput = 0;
}

void TemperatureController::service(int currentTempF, ulong currentTimeMSec)
{

    BangBangState controlOutput;

#ifdef DEBUG_TEMPERATURE_CONTROLLER
    DEBUG_PRINTLN();
    DEBUG_PRINTLN("TC::service() - Entry");
#endif

    // Check if the controller needs to be serviced
    if (currentTimeMSec - m_lastServiceTimeMSec < m_config.temperatureIntervalMSec)
    {
        return; // Not enough time has passed since the last service
    }
    m_lastServiceTimeMSec = currentTimeMSec;

    // Check for updated configuration values
    m_bangBang.setThresholds(m_config.bangBangLowThreshold, m_config.bangBangHighThreshold);
    m_bangBang.setHysteresis(m_config.bangBangHysteresis);
    m_pid.setKp(m_config.kP);
    m_pid.setKi(m_config.kI);
    m_pid.setKd(m_config.kD);

    // Figure out which control algorithm to use - may get more complicated later
    if (m_config.isPIDEnabled)
    {
        m_algorithm = CONTROL_PID;
    }
    else
    {
        m_algorithm = CONTROL_BANGBANG;
    }

    switch (m_algorithm)
    {
    case CONTROL_PID:

        servicePIDController(currentTempF, m_status.temperatureTarget, currentTimeMSec);
        break;

    case CONTROL_BANGBANG:

        serviceBangBangController(currentTempF, m_status.temperatureTarget, currentTimeMSec);

        break;

    default:
        break;
    }

#ifdef DEBUG_TEMPERATURE_CONTROLLER
    DEBUG_PRINTLN("TC::service() - Exit");
#endif
}

int TemperatureController::getLastOutput()
{
    return m_lastOutput;
}

void TemperatureController::serviceBangBangController(int currentTempF, int targetTempF, ulong currentTimeMSec)
{
    BangBangState controlOutput = m_bangBang.service(currentTempF, currentTimeMSec);
    m_lastOutput = static_cast<int>(controlOutput); // Store the last output for reference
    switch (controlOutput)
    {
    case BANGBANG_STATE_IDLE:
        // If the state is IDLE, stop the blower and set door position
        m_blower.setPWM(0);
        m_door.open();
        break;
    case BANGBANG_STATE_HEAT:
        // If the state is HEAT, start the blower and open the door
        m_blower.setPWM(m_config.bangBangFanSpeed);
        m_door.open();
        break;
    case BANGBANG_STATE_COOL:
        // If the state is COOL, stop the blower and close the door
        m_blower.setPWM(0);
        m_door.close();
        break;
    default:
        break;
    }
}

void TemperatureController::servicePIDController(int currentTempF, int targetTempF, ulong currentTimeMSec)
{

    // Call the PID service to calculate the control output
    int controlOutput = m_pid.service(currentTempF, targetTempF, currentTimeMSec);
    m_lastOutput = controlOutput; // Store the last output for reference
#ifdef DEBUG_TEMPERATURE_CONTROLLER
    DEBUG_PRINTLN("TC::PID - CONTROL: " + String(controlOutput));
#endif

    // Check whether the blower or the door should be activated
    if (controlOutput > 0)
    {
#ifdef DEBUG_TEMPERATURE_CONTROLLER
        DEBUG_PRINTLN("TC::PID - HEATING");
#endif
        // Truncate the control output to the range of 0-255
        controlOutput = constrain(controlOutput, 0, 255);
        m_blower.setPWM(controlOutput);
        m_door.open();
    }
    else
    {
#ifdef DEBUG_TEMPERATURE_CONTROLLER
        DEBUG_PRINTLN("TC::PID - COOLING");
#endif
        // If the control output is less than or equal to 0, stop the blower and close the door
        m_blower.setPWM(0);
        m_door.close();
    }
}

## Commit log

2025-05-31 Refactor Motor class into Blower class
2025-06-02 Update types.h
    Renamed DeviceStatus into ControllerStatus and separated control session time from the uptime
2025-06-02 In Knob class added ultra long button press state (10 seconds, hardcoded)
2025-06-02 Add ultra long button press functionality to reset ESP32 and NVRAM
    [main.cpp]
2025-06-02 Handle short button press in knob class to trigger command selection in GUI
    [main.cpp]
2025-06-02 Clear NVRAM and reset ESP32 on ultra long button press
    [main.cpp]
2025-06-02 First implementation of the PID controller
2025-06-03 Passing current time msec into the bangbang controller for future use in the ramp up time calculation
2025-06-03 First implementation of the temperaturecontroller class
2025-06-03 Added temperature controller into the main loop
2025-06-03 Debugging statements added to the temperaturecontroller class
2025-06-03 Added compile level option for the temperature controller to simulate temperature readings (sine wave)
2025-06-03 Reference to the temperaturecontroller added to main.h
2025-06-03 Added detection of the temperature controller being disabled and triggered the blower stop and door close on that action.
2025-06-03 Door issues troubleshooting check point
    [door.cpp, door.h, main.cpp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]
2025-06-04 Bug fixes in door class
    [door.cpp, door.h, main.cpp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]
2025-06-04 Fixed the scaling issues when displaying the door position on the display panel
    [gui.cpp, gui.h, main.cpp]
2025-06-06 Add PlatformIO debugging configuration for ESP32 project
    - Created a new launch.json file in the .vscode directory.
    - Added multiple debugging configurations for the ESP32 development environment:
    - Standard PIO Debug
    - PIO Debug (skip Pre-Debug)
    - PIO Debug (without uploading)
    - Configurations include paths to the executable, project environment name, and toolchain binary directory.
2025-06-07 Fixed bug with the food and smoker spectrometer having swapped pins.
    [main.cpp, main.h]
2025-06-07 Added error term output to the temperature controller class
    [temperaturecontroller.cpp]
2025-06-09 Add temperature error field to ControllerStatus and update loop to log last temperature output
    [main.cpp]
2025-06-09 Add temperature error field to API status response
    [webserver.cpp]
2025-06-09 Add Temperature and TemperatureBar components for displaying temperature readings
2025-06-09 Add TemperatureHistoryChart component for visualizing temperature data
2025-06-09 Add CSS styles for temperature display components
2025-06-09 Add StatusBanner and StatusBar components with styling for device status display
2025-06-09 Add DeviceConfig and DeviceStatus interfaces with default configurations
2025-06-09 Add main HTML structure and implement real-time device status fetching in App component
2025-06-10 Bug fix: connectToWiFi was not declared in main.h
    [main.h]
2025-06-10 Implemented structure for handling temperature profiles, and support of that structure via GUI
2025-06-10 Integration of temperature profiling into the temperaturecontroller class and into the main loop
2025-06-11 Temperature profile handling in loop and updateControllerStatus functions
2025-06-11 Refactor temperature profile duration handling to allow finer adjustments in increment and decrement functions
2025-06-11 Add temperature profile tracking fields to ControllerStatus struct
2025-06-11 Support new DeviceStatus definition with temperature profile in the front end
2025-06-11 Update device status handling and fix temperature target reference in TemperatureBar component
2025-06-11 Add temperature profile fields to status log in Database class
2025-06-11 Added missing fields associated with the temperature profiling to the get requests
    [webserver.cpp]
2025-06-11 Enhance temperature profiling support in status and configuration endpoints
2025-06-12 Fixed the typo in the temperature profile structure
    [gui.cpp, main.cpp, webserver.cpp]
2025-06-17 Added minimum PWM level for the Blower
2025-06-17 Remove debugging code and motor ID from Blower class
2025-06-17 Refactored the Blower class to add low speed mode to operate sub minimum safe PWM
2025-06-17 Bug fixes in the blower low speed state
    [blower.cpp]
2025-06-17 Add forced fan PWM control for blower motor when not running
2025-06-17 Disable debugging flag for temperature controller
2025-06-20 Implement temperature filtering functionality with EWMA support and added required new fields to the configuration structure and the GUI
2025-06-20 Added step files for all 3d printed hardware components
    [TB6612FNG_holder_left.step, TB6612FNG_holder_right.step, airflow_damper.step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]
2025-06-20 Added images of printed parts
2025-06-21 Added images of the smokemate assembly
